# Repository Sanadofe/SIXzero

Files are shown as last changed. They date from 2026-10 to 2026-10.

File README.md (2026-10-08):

***This is SIXzero's public repository.***

***SIXzero is a 60° wedge alarm clock with mechanical keys and a blue color display, inspired by 1970s tech.***

***SCHEMATIC***


***PCB***





***Inspiration***

I based this on 1970s computer terminals, the grey or cream colored ones with the screen leaning back over the keyboard. Mine sits at 60°, which is where the name comes from.

**These are some of the inspo images**





***Photo BANK:***

**Overview Photo**

SIX-zero iso compo

**Exploded View**

SIXzero Exploded view compo

**Front Photo**

SIX-zero front compo

**Side Photo**

SIX-zero side compo

**Top photo**

SIX-zero top view compo

***Bill of Materials***

Part,Description,Qty
| Part | Description | Qty |
|---|---|---|
| Seeed XIAO ESP32C3 | Microcontroller | 1 |
| MX-style keyboard switch | KS-3Y10B050NW-X1 Yellow | 4 |
| White blank DSA keycap | 1u | 4 |
| 2.25in TFT display | ST7789 76x284 | 1 |
| 3.3V piezo buzzer | Through-hole | 1 |
| Pin header 1x8 male 2.54mm | Screen and PCB | 2 |
| Pin header 1x7 male 2.54mm | For XIAO | 2 |
| Jumper wire female-female 20cm | Screen to PCB | 8 |
| sixzero PCB | 90 x 62 mm | 1 |
| Heatset insert M3x5x4 | Threaded insert | 8 |
| Screw M3x8mm | PCB mount | 4 |
| Screw M3x16mm | Lid | 4 |
| PLA filament matte | Cream or grey | 1 |
| Acrylic paint | Lettering | 1 |
| Foam tape or hot glue | Screen mount | 1 |
| USB-C data cable | Power and upload | 1 |

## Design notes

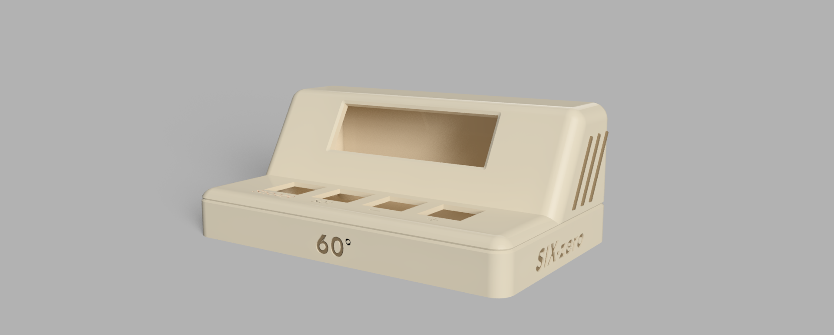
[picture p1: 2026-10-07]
PICTURES/SIX-zero iso no compo.png

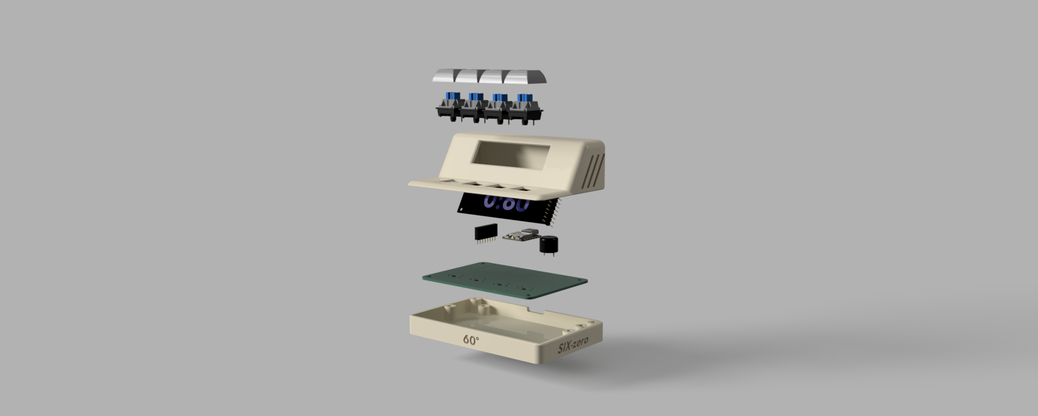
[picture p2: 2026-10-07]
PICTURES/SIXzero Exploded view compo.png

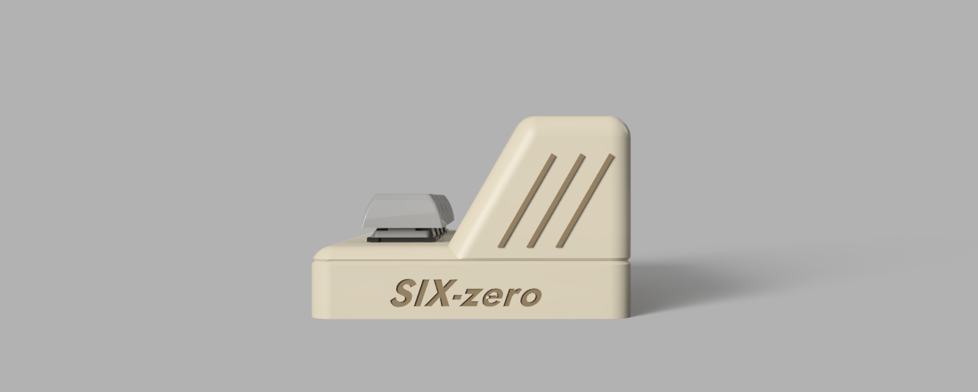
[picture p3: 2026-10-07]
PICTURES/SIX-zero side compo.png

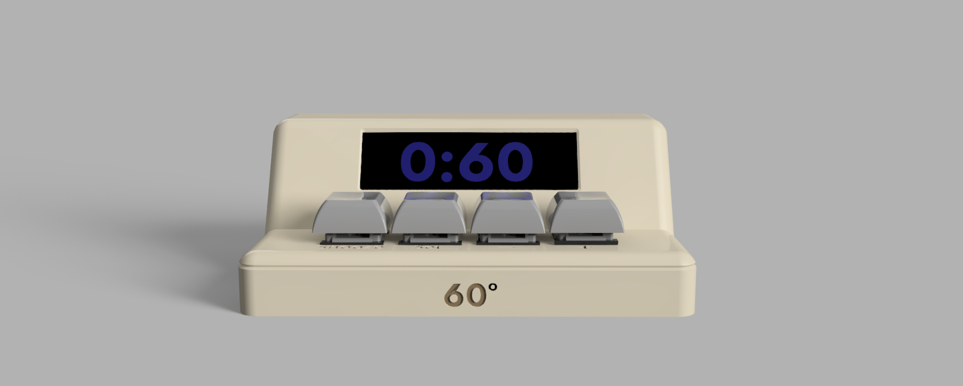
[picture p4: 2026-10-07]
PICTURES/SIX-zero front compo.png

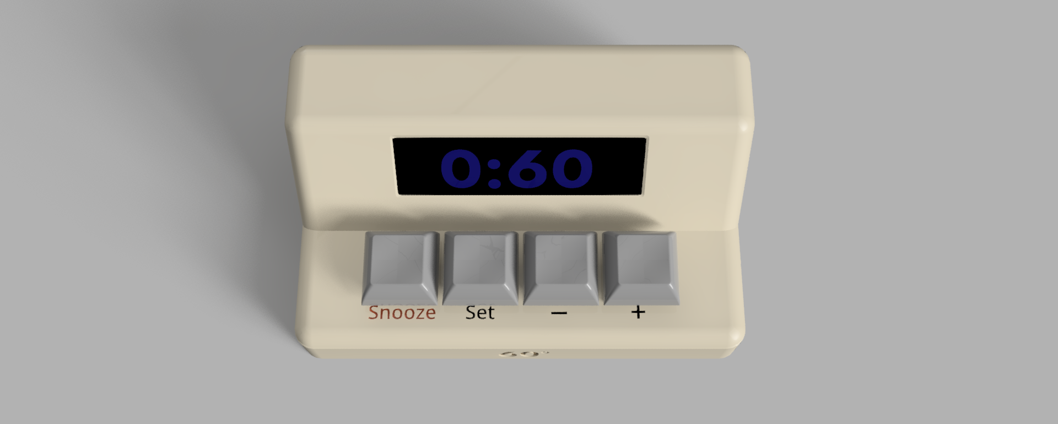
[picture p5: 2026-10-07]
PICTURES/SIX-zero top view compo.png

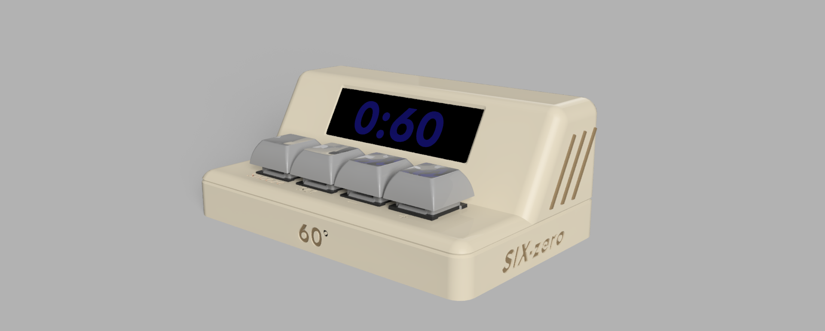
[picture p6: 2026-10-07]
PICTURES/SIX-zero iso compo.png

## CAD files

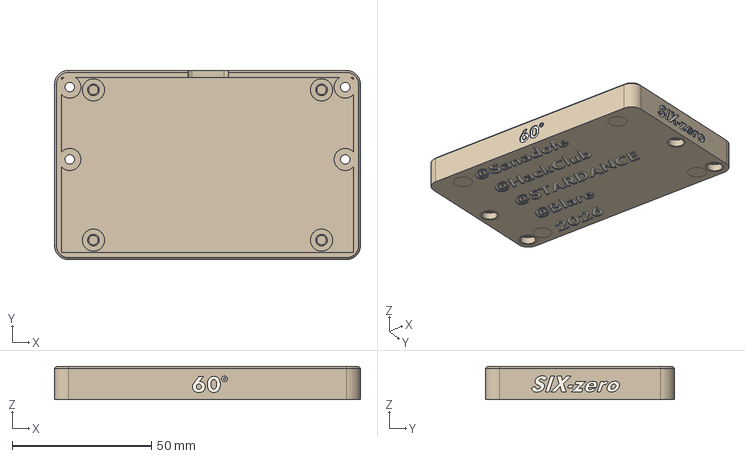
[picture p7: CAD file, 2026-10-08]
CAD/SIXzero Base .Step v2.step
110.0 x 68.0 x 12.0 mm

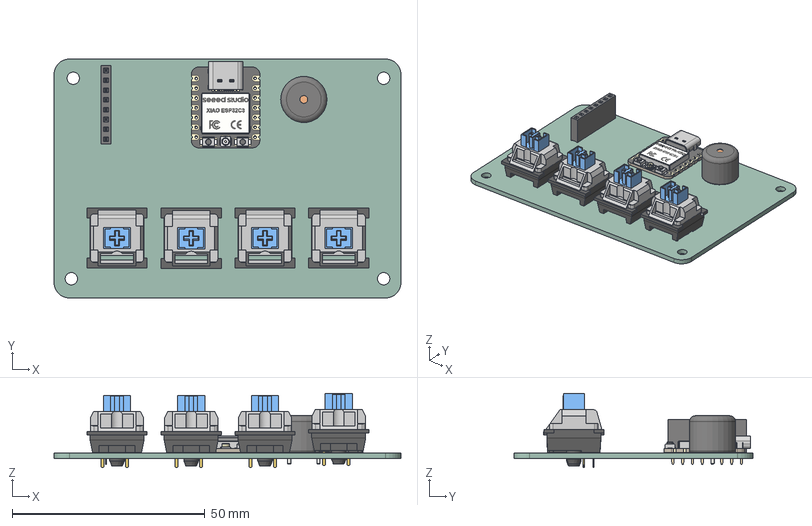
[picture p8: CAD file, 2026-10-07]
PCB/ALARM CLOCK snoozless STEP PCB.step
90.0 x 62.0 x 19.2 mm
PinSocket_1x08_P2.54mm_Vertical
Buzzer_12x95RM76
Button x 4
Pins x 4
BOSS-EXTRUDE14_8_
BOSS-EXTRUDE7_4_
BOSS-EXTRUDE7_3_
BOSS-EXTRUDE14_4_
BOSS-EXTRUDE14_2_
BOSS-EXTRUDE14_11_
BOSS-EXTRUDE7_7_
BOSS-EXTRUDE14_9_
BOSS-EXTRUDE14_3_
BOSS-EXTRUDE14_7_
MIRROR2
BOSS-EXTRUDE14_5_
BOSS-EXTRUDE14_12_
BOSS-EXTRUDE7_8_
BOSS-EXTRUDE7_1_
BOSS-EXTRUDE14_10_
BOSS-EXTRUDE7_9_
BOSS-EXTRUDE14_6_
BOSS-EXTRUDE14_1_
BOSS-EXTRUDE7_6_
BOSS-EXTRUDE7_2_
CUT-EXTRUDE5
BOSS-EXTRUDE7_5_
U.FL Connector v1
Button (1) x 2
Shield
ALA613C_PCB

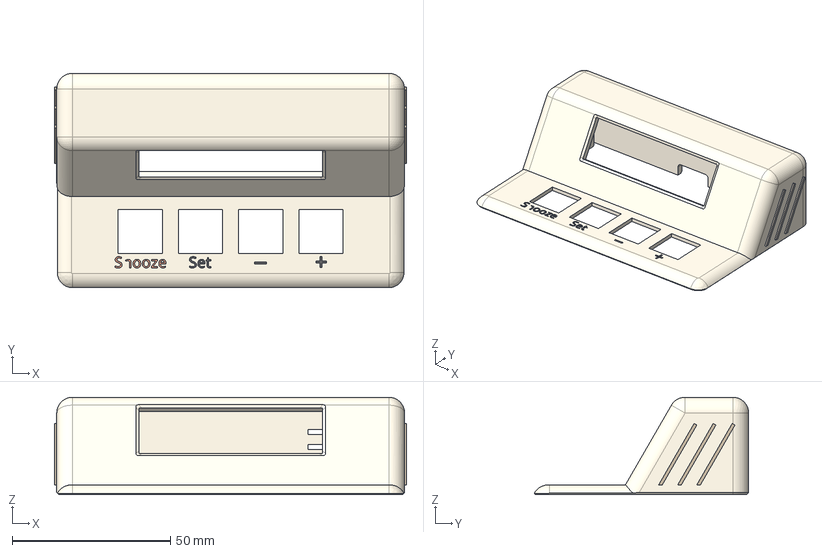
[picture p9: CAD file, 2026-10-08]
CAD/SIXzero TOP .step.step
111.3 x 67.8 x 30.8 mm

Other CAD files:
Production/SIXzero 3mf Bottom.3mf
Production/SIXzero 3mf Top.3mf
CAD/SIXzero Full assembly.f3z

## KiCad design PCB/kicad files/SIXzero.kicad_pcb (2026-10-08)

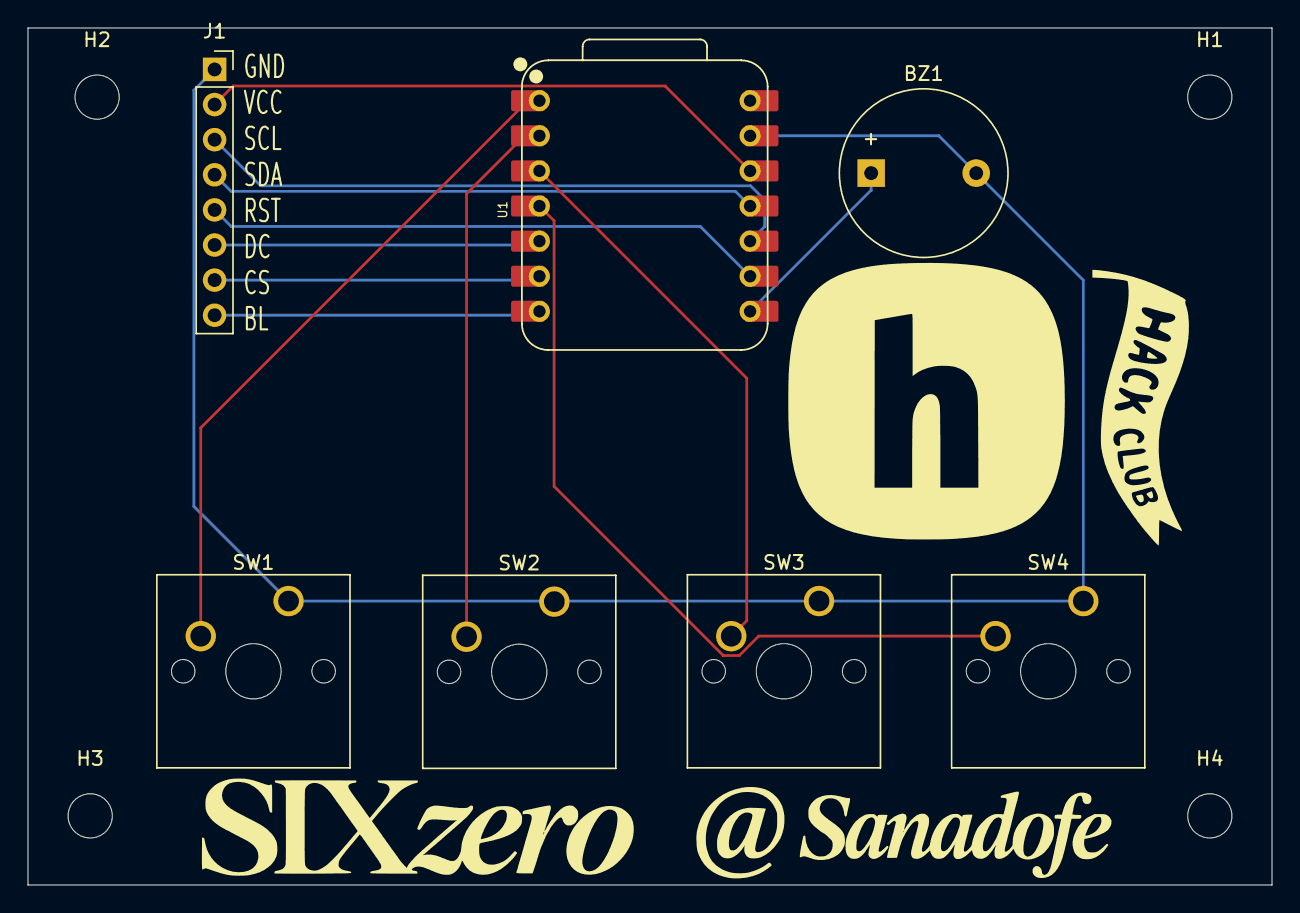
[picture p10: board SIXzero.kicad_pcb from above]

Board: 2 copper layers, 90.0 x 62.0 mm, 11 parts (0 on the bottom side), 13 nets.

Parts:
BZ1: Buzzer; Buzzer_12x9.5RM7.6
H1, H2, H3, H4: MountingHole; MountingHole_3.2mm_M3
J1: Conn_01x08_Pin; PinSocket_1x08_P2.54mm_Vertical
SW1, SW2, SW3, SW4: SW_Push; SW_Cherry_MX_1.00u_PCB
U1: XIAO-ESP32-C3-SMD; XIAO-ESP32-C3-DIP

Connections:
+3.3V: J1.2, U1.12 (3V3_OUT)
GND: BZ1.2 (-), J1.1, SW1.1, SW2.1, SW3.1, SW4.1, U1.13 (GND)
unnamed: BZ1.1 (+), U1.8 (D7)
unnamed: J1.3, U1.10 (D9/BOOT)
unnamed: J1.4, U1.11 (D10)
unnamed: J1.5, U1.9 (D8)
unnamed: J1.6, U1.5 (D4)
unnamed: J1.7, U1.6 (D5)
unnamed: J1.8, U1.7 (D6)
unnamed: SW1.2, U1.1 (D0)
unnamed: SW2.2, U1.2 (D1)
unnamed: SW3.2, U1.3 (D2)
unnamed: SW4.2, U1.4 (D3)

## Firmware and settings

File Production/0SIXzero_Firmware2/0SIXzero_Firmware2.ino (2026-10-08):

#include <Preferences.h>
#include <WiFi.h>
#include <time.h>
#include <Adafruit_GFX.h>
#include <Adafruit_ST7789.h>
#include <SPI.h>

const char* WIFI_SSID = "MY_WIFI_NAME"; //2.4 GHz network only 
const char* WIFI_PASS = "MY_WIFI_PASSWORD";
const char* TZ_INFO = "NZST-12NZDT,M9.5.0,M4.1.0/3"; //NZ with daylight saving
bool ntpStarted = false;

const int PIN_SNOOZE = D0; 
const int PIN_SET    = D1;
const int PIN_MINUS  = D2; 
const int PIN_PLUS   = D3; 

const uint32_t HOLD_MS = 2000;

const int PIN_DC = D4;
const int PIN_CS = D5;
const int PIN_BL = D6;
const int PIN_SCL = D9;
const int PIN_SDA =D10;
const int PIN_RST = D8;

class MyST7789 : public Adafruit_ST7789 {
public: 
 MyST7789(SPIClass* spi, int8_t cs, int8_t dc, int8_t rst)
 : Adafruit_ST7789(spi, cs, dc, rst){}
 void setOffsets(uint8_t col, uint8_t row) {
  _colstart = _colstart2 = col;
  _rowstart = _rowstart2 = row;
 }
};

MyST7789 tft(&SPI, PIN_CS, PIN_DC, PIN_RST);
GFXcanvas16* canvas = nullptr;

enum Ev { EV_NONE, EV_PRESS, EV_SHORT, EV_HOLD };

struct Btn {
  uint8_t  pin;
  bool     down, raw, holdFired;
  uint32_t changed, downAt;
  Btn(uint8_t p) : pin(p), down(false), raw(false), holdFired(false), changed(0), downAt(0) {}
};

Btn bSnooze(PIN_SNOOZE), bSet(PIN_SET), bMinus(PIN_MINUS), bPlus(PIN_PLUS);
Ev poll(Btn& b) {
  bool r = (digitalRead(b.pin) == LOW);
  uint32_t now = millis();
  if (r != b.raw) { b.raw = r; b.changed = now; }
  Ev ev = EV_NONE;
  if ((now - b.changed) > 25 && r != b.down) {
 b.down = r;
    if (r) { b.downAt = now; b.holdFired = false; ev = EV_PRESS; }
    else if (!b.holdFired) ev = EV_SHORT;
  }
  if (b.down && !b.holdFired && (now - b.downAt) >= HOLD_MS) {
    b.holdFired = true;
    ev = EV_HOLD;
  }
  return ev;
}

const int PIN_BUZZ = D7;
const bool BUZZER_ACTIVE = false;  // change if it was active buzzer, to true 
const int BUZZER_HZ = 2700;

void buzzTone(int f) {
  #if ESP_ARDUINO_VERSION_MAJOR >=3 
  ledcWriteTone(PIN_BUZZ, f);
  #else 
  ledcWriteTone(0, f);
  #endif
}
void buzzInit() { 
  if (BUZZER_ACTIVE) { 
    pinMode(PIN_BUZZ, OUTPUT);
    digitalWrite(PIN_BUZZ, LOW);
  } else { 
  #if ESP_ARDUINO_VERSION_MAJOR >=3
      ledcAttach(PIN_BUZZ, 2000, 8 );
  #else 
  ledcSetup(0, 2000 ,8);
  ledcAttachPin(PIN_BUZZ, 0); 
  #endif
  buzzTone(0);
  }
}
void buzzOff() { 
  if (BUZZER_ACTIVE) digitalWrite(PIN_BUZZ, LOW);
  else buzzTone(0);
}

int      alarmH = 7, alarmM = 0;
bool     alarmOn = true;           // true for now, for testing
const int SNOOZE_MINUTES = 9;
bool     ringing = false, snoozed = false;
time_t   snoozeUntil = 0;
uint32_t ringStart = 0;
long     lastTrigger = -1;

void startRinging() { ringing = true; snoozed = false; ringStart = millis(); Serial.println("ringing"); }
void stopAlarm()    { ringing = false; snoozed = false; buzzOff(); Serial.println("stopped"); }

// four short beeps, a pause, repeat. After 30 s it gets faster.
void alarmSound() {
  bool fast = (millis() - ringStart) > 30000;
  uint32_t cycle = fast ? 500 : 2000;
  uint32_t m = millis() % cycle;
  bool on = fast ? ((m % 125) < 60) : (m < 1000 && (m % 250) < 125);
  if (BUZZER_ACTIVE) digitalWrite(PIN_BUZZ, on ? HIGH : LOW);
  else buzzTone(on ? BUZZER_HZ : 0);
}

enum Mode {CLOCK, SET_HOUR, SET_MIN, SET_ON};
Mode mode = CLOCK; 
uint32_t lastInput = 0;
Preferences prefs; 

void loadSettings() { 
 prefs.begin("sixzero", true);
 alarmH = prefs.getInt("h", 7);
 alarmM = prefs.getInt("m", 0);
 alarmOn = prefs.getBool("on", false);
 prefs.end();
} 

void saveSettings() {
  prefs.begin("sixzero", false);
  prefs.putInt("h", alarmH);
  prefs.putInt("m", alarmM);
  prefs.putBool("on", alarmOn);
  prefs.end(); 
}

void setup() {
  Serial.begin(115200);
  pinMode(PIN_SNOOZE, INPUT_PULLUP);
  pinMode(PIN_SET,    INPUT_PULLUP);
  pinMode(PIN_MINUS,  INPUT_PULLUP);
  pinMode(PIN_PLUS,   INPUT_PULLUP);

  loadSettings();
  buzzInit();

  pinMode(PIN_BL, OUTPUT);
  digitalWrite(PIN_BL, LOW);            // LOW = backlight ON on this module
  SPI.begin(PIN_SCL, -1, PIN_SDA, -1);  // clock, no MISO, data
  tft.init(76, 284);
  tft.setOffsets(82, 18);
  tft.invertDisplay(false);
  tft.setRotation(1);
  tft.fillScreen(ST77XX_BLACK);
  canvas = new GFXcanvas16(tft.width(), tft.height());

  WiFi.mode(WIFI_STA);
  WiFi.begin(WIFI_SSID, WIFI_PASS);
  lastInput = millis();
}

 void drawSimple(const tm& t, bool timeValid) {
  canvas->fillScreen(0x0000);
  canvas->setTextSize(6);
  canvas->setTextColor(0x03DF); // Bright blue 
  canvas->setCursor(6, 14);
  char buf[8];
  if (timeValid) snprintf(buf, sizeof buf, "%02d:%02d", t.tm_hour, t.tm_min);
  else snprintf(buf, sizeof buf, "--:--");
  canvas->print(buf);
  tft.drawRGBBitmap(0, 0, canvas->getBuffer(), canvas->width(), canvas->height());
}

void loop() {
  uint32_t nowMs = millis();

  // Wi-Fi time 
  if (!ntpStarted && WiFi.status() == WL_CONNECTED) {
    configTzTime(TZ_INFO, "pool.ntp.org", "time.cloudflare.com");
    ntpStarted = true;
  }
  time_t nowT = time(nullptr);
  bool timeValid = (nowT > 1700000000);
  struct tm t;
  localtime_r(&nowT, &t);

  // buttons 
  Ev eSn = poll(bSnooze), eSet = poll(bSet), eMinus = poll(bMinus), ePlus = poll(bPlus);
  if (eSn || eSet || eMinus || ePlus) lastInput = nowMs;

  if (ringing) {
    // ringing: snooze or stop 
    if (eSn == EV_SHORT) {
      ringing = false;
      snoozed = true;
      snoozeUntil = nowT + SNOOZE_MINUTES * 60;
      buzzOff();
    } else if (eSn == EV_HOLD) {
      stopAlarm();
    }
  } else if (snoozed && eSn == EV_HOLD) {
    stopAlarm();
  } else {
    // not ringing: set the alarm 
    switch (mode) {
      case CLOCK:
        if (eSet == EV_SHORT) mode = SET_HOUR;
        break;
      case SET_HOUR:
        if (ePlus == EV_PRESS)  alarmH = (alarmH + 1) % 24;
        if (eMinus == EV_PRESS) alarmH = (alarmH + 23) % 24;
        if (eSet == EV_SHORT)   mode = SET_MIN;
        break;
      case SET_MIN:
        if (ePlus == EV_PRESS)  alarmM = (alarmM + 1) % 60;
        if (eMinus == EV_PRESS) alarmM = (alarmM + 59) % 60;
        if (eSet == EV_SHORT)   mode = SET_ON;
        break;
      case SET_ON:
        if (ePlus == EV_PRESS || eMinus == EV_PRESS) alarmOn = !alarmOn;
        if (eSet == EV_SHORT) {
          saveSettings();
          lastTrigger = -1;
          if (!alarmOn) stopAlarm();
          mode = CLOCK;
        }
        break;
    }
    // leave set mode after 15 s of no input
    if (mode != CLOCK && (nowMs - lastInput) > 15000) {
      saveSettings();
      if (!alarmOn) stopAlarm();
      mode = CLOCK;
    }
  }

  // alarm trigger 
  if (timeValid && alarmOn && !ringing) {
    long key = (long)t.tm_yday * 1440 + t.tm_hour * 60 + t.tm_min;
    if (!snoozed && t.tm_hour == alarmH && t.tm_min == alarmM && key != lastTrigger) {
      lastTrigger = key;
      startRinging();
    }
    if (snoozed && nowT >= snoozeUntil) startRinging();
  }

  // give up after 10 minutes
  if (ringing && (nowMs - ringStart) > 10UL * 60UL * 1000UL) stopAlarm();

  // sound
  if (ringing) alarmSound();

  static uint32_t lastDraw = 0;
  if (nowMs - lastDraw >= 200) {
    lastDraw = nowMs;
    drawSimple(t, timeValid);
  }
}

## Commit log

2026-10-07 Add Bill of Materials to README
    Added a Bill of Materials section with components and quantities.
2026-10-07 Fix formatting and add bom.csv link in README
    Updated README.md to include a link to bom.csv and corrected formatting for the Bill of Materials section.
2026-10-07 Revise Bill of Materials and remove bom.csv link
    Updated the Bill of Materials section and removed the link to bom.csv.
2026-10-07 Refactor Bill of Materials to markdown table format
    Updated the Bill of Materials section to use a markdown table format for better readability.
2026-10-08 Added updated CAD
2026-10-08 Update README with schematic and PCB images
    Added schematic and PCB images to README.
2026-10-08 Update README with PCB images
    Added PCB images to the README for better visualization.
